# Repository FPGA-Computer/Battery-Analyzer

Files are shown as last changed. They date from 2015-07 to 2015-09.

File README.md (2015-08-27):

This is a Dual Channel Battery Analyzer for HaD 2015 Contest Entry.

+ Ver 2.1 Rel 0/	
|  |Initial PCB release - first layout/non-tested
|  |
|  + Eagle PCB/
|  | Eagle CAd files
|  |
|  + Sketch3D/
|  | Sketch3D model
|  |
|  + LTSpice/
|    Linear Tech Spice Simulation analog file
|
+ Windows/
| Pelles C Project file
|
+ Firmware/
  Simplicity Studio files

Hackaday project page is at 
https://hackaday.io/project/4993-dual-channel-battery-chargeranalyzer

The hardware design is under a Creative Commons Attribution-
NonCommercial-ShareAlike 4.0 International License.

The full detail of this license is available at: 
http://creativecommons.org/licenses/by-nc-sa/4.0/

The software is under Mozilla Public License
The full detail of this license is available at: 
https://www.mozilla.org/MPL/

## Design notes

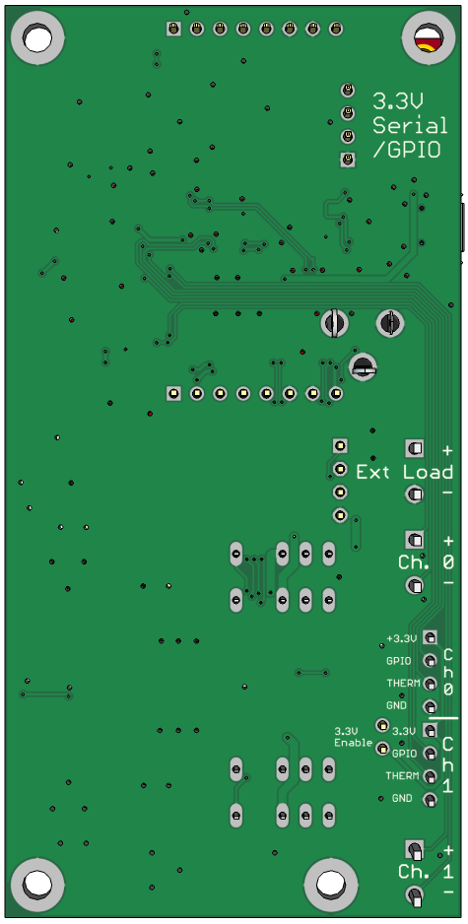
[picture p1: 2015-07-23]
Ver 2.1 Rel 0/Sketch3D/pcb-bot.png

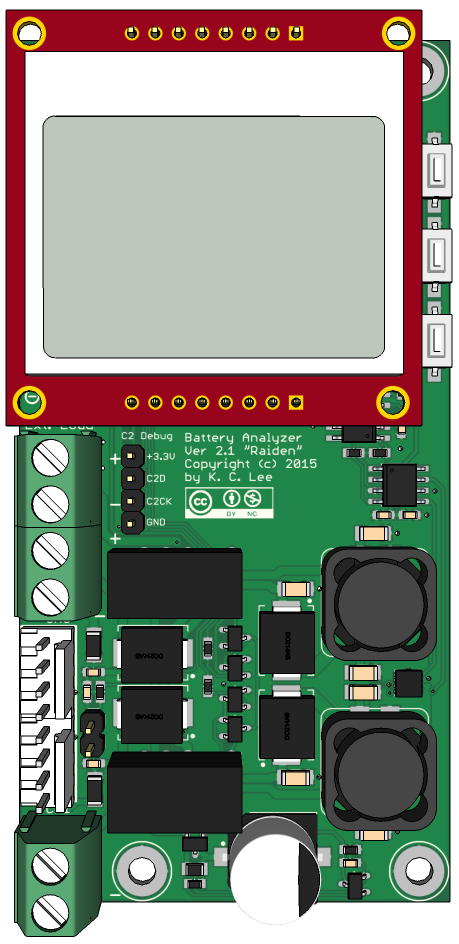
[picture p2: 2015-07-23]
Ver 2.1 Rel 0/Sketch3D/PCB-top.png

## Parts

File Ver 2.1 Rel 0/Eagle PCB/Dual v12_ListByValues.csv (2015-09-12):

Qty | Value | Part Num | Package | Parts
1 |  | BG: SKU038984 | 1X02 | J2
1 |  | BG: SKU038984 | 1X04 | JP1
1 |  | DX: SKU134132 | USB-AB-MICRO-SMD_V03_SF | U1
1 |  | STOCK | 1X04-RA | JP2
4 | 0.01uF | DK: 311-1085-1-ND | CAPC1608X92N | C20, C21, C22, C23
2 | 0R1 .25W | STOCK: DK73L4R10JCT-ND | RESC3115X70N | R18, R21
12 | 0u1 | STOCK: DK 490-1532-1-ND | CAPC1608X92N | C2, C6, C7, C13, C15, C16, C17, C18, C19, C24, C33, C34
5 | 0u1 | STOCK: DK 587-1227-1-ND | CAPC1005X60N | C5, C29, C30, C31, C32
2 | 0u15/50V | STOCK: 0.15UF/50V10% | CAP2012X70N | C1, C12
1 | 1K | DK: 311-1.00KLRCT-ND | RESC1005X40AN | R5
1 | 1K | STOCK: DK 1276-3484-1-ND | RESC1608X55N | R4
4 | 1K2 | STOCK: 1K21 1% | RESC1608X55N | R7, R26, R28, R29
2 | 1K5 | STOCK: DKRHM1.50KCFCT-ND | RESC1608X55N | R17, R20
1 | 1nF | DK: 311-1080-1-ND | CAPC1608X92N | C25
2 | 1uF | DK: 490-10435-1-ND | CAPC1005X60N | C3, C4
4 | 1uF | STOCK: 1UF/10V 20% TDK | CAPC1608X92N | C10, C26, C27, C35
3 | 1uF/25V | DK: 311-1456-1-ND | CAP2012X70N | C9, C11, C14
2 | 4K7 | STOCK:4K75 1% | RESC1608X55N | R14, R27
1 | 8K2 | STOCK | CAT16 | RN2
10 | 10K | STOCK: 10K 1% | RESC1608X55N | R2, R16, R19, R24, R25, R31, R33, R34, R35, R36
2 | 10K | STOCK: DK CAY16-103J4GLFCT-ND | CAT16 | RN3, RN4
1 | 10R | STOCK: 10R 1% | RESC1608X55N | R15
1 | 10uF/6.3V | DK: 490-5525-1-ND | CAP2012X70N | C42
2 | 10uF/16V | DK: 490-5525-1-ND | CAPC3215X168N | C37, C39
2 | 10uF/25V | DK: 490-5525-1-ND | CAPC3215X168N | C40, C41
2 | 10uF/35V | DK: 490-9964-1-ND | CAPC3215X168N | C36, C38
1 | 13K0 | DK: 311-13.0KHRCT-ND | RESC1608X55N | R9
2 | 22-23-2041 | DK: A19431-ND | 22-23-2041 | J4, J5
2 | 22R | STOCK: DK 1276-3497-1-ND | RESC1608X55N | R1, R3
1 | 22pF | STOCK: 22PF | CAPC1608X92N | C28
5 | 39K2 | DK: 311-39.2KHRCT-ND | RESC1608X55N | R12, R22, R23, R32, R37
1 | 100K | STOCK: DK311-100KHRCT-ND | RESC1608X55N | R6
2 | 100R | STOCK | RESC1608X55N | R11, R13
1 | 100R | STOCK | RESC2012X70N | R8
1 | 470R | DK: YC164J-470CT-ND | CAT16 | RN1
1 | 470uF/25V | STOCK | CAPAE1030X1020N | C8
1 | 475K | STOCK: P475KHCT-ND | RESC1608X55N | R10
1 | 475R | STOCK: DK 1276-4620-1-ND | RESC1608X55N | R30
1 | AON7804 | DK: 785-1586-1-ND | DFN3X3 | Q7
1 | AP3012 | DK: AP3012KTR-G1DICT-ND | SOT23-5 | U3
1 | BAT54C | STOCK | SOT95P280X135-3N | D3
1 | CC100% | * | CC-100 | U$1
1 | CCNONE | * | CC-NONE | U$2
2 | CD54NP-100MC | DK: 587-1626-1-ND | CD54 | L1, L2
1 | DCJ0202PIN | STOCK: DK CP-102A-ND | PJ-102A | J1
1 | EFM8UB1X-QFN28 | DK: 336-3183-5-ND | QFN-28 | U2
2 | G6N-2-Y | STOCK | NA | K1, K2
1 | LM339D | STOCK | SO14 | U5
6 | MBRS430 | STOCK | DIOM7959X265N | D1, D2, D10, D11, D12, D13
3 | MMBT2222 | STOCK: MMBT2222 | SOT95P280X135-3N | Q3, Q5, Q6
2 | MMBT3906 | STOCK:MMBT3906 | SOT95P280X135-3N | Q1, Q4
3 | MOM_SW__1181 | BG: SKU156899 | MOM-1181 | S1, S2, S3
4 | MOUNT-PAD-ROUND3.2 | * | 3,2-PAD | H1, H2, H3, H4
1 | NOKIA5110 | BG: SKU091069 | NOKIA5110-BOTH | U4
1 | POLARITY | * | POLARITY | U$3
3 | SCREW-TERM_5MM_BG | BG: SKU170379 | 1X02-5MM-BG | J3, J6, J7
2 | SRF1260-100M | DK: SRF1260-100MCT-ND | SRF1260 | L3, L4
1 | STPS130A | DK: 497-3755-1-ND | DIOM5326X292N | D4
4 | Si SW | STOCK: BAV99 | SOT95P280X135-3N | D6, D7, D8, D9
1 | Si2307 | STOCK: SI2307DS | SOT95P280X135-3N | Q2
1 | TC4426ACOA | DK: TC4426ACOA-ND | SOIC8 | U6
1 | TPSQTP08R | * | TP08R | TP1
2 | TPSQTP14SQ | * | TP14SQ | TP2, TP3
1 | Z12V | STOCK | SOT95P280X135-3N | D5

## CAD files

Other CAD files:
Windows/charger21/output/debug.obj
Windows/charger21/output/usb host.obj
Windows/charger21/output/Charger gui.obj
Windows/charger21/output/data.obj
Windows/charger21/output/Battery gui.obj
Windows/charger21/output/charger.obj
Windows/charger21/output/gui support.obj
Windows/charger21/output/fileop.obj
Windows/charger21/output/tabmenu.obj

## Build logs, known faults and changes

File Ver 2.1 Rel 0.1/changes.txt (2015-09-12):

- Fixed connections with VBUS detection
- 0402 parts switched to 0603 and cap array.
- todo need new lcd footprint

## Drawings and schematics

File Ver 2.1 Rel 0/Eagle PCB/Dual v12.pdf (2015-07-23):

A

A

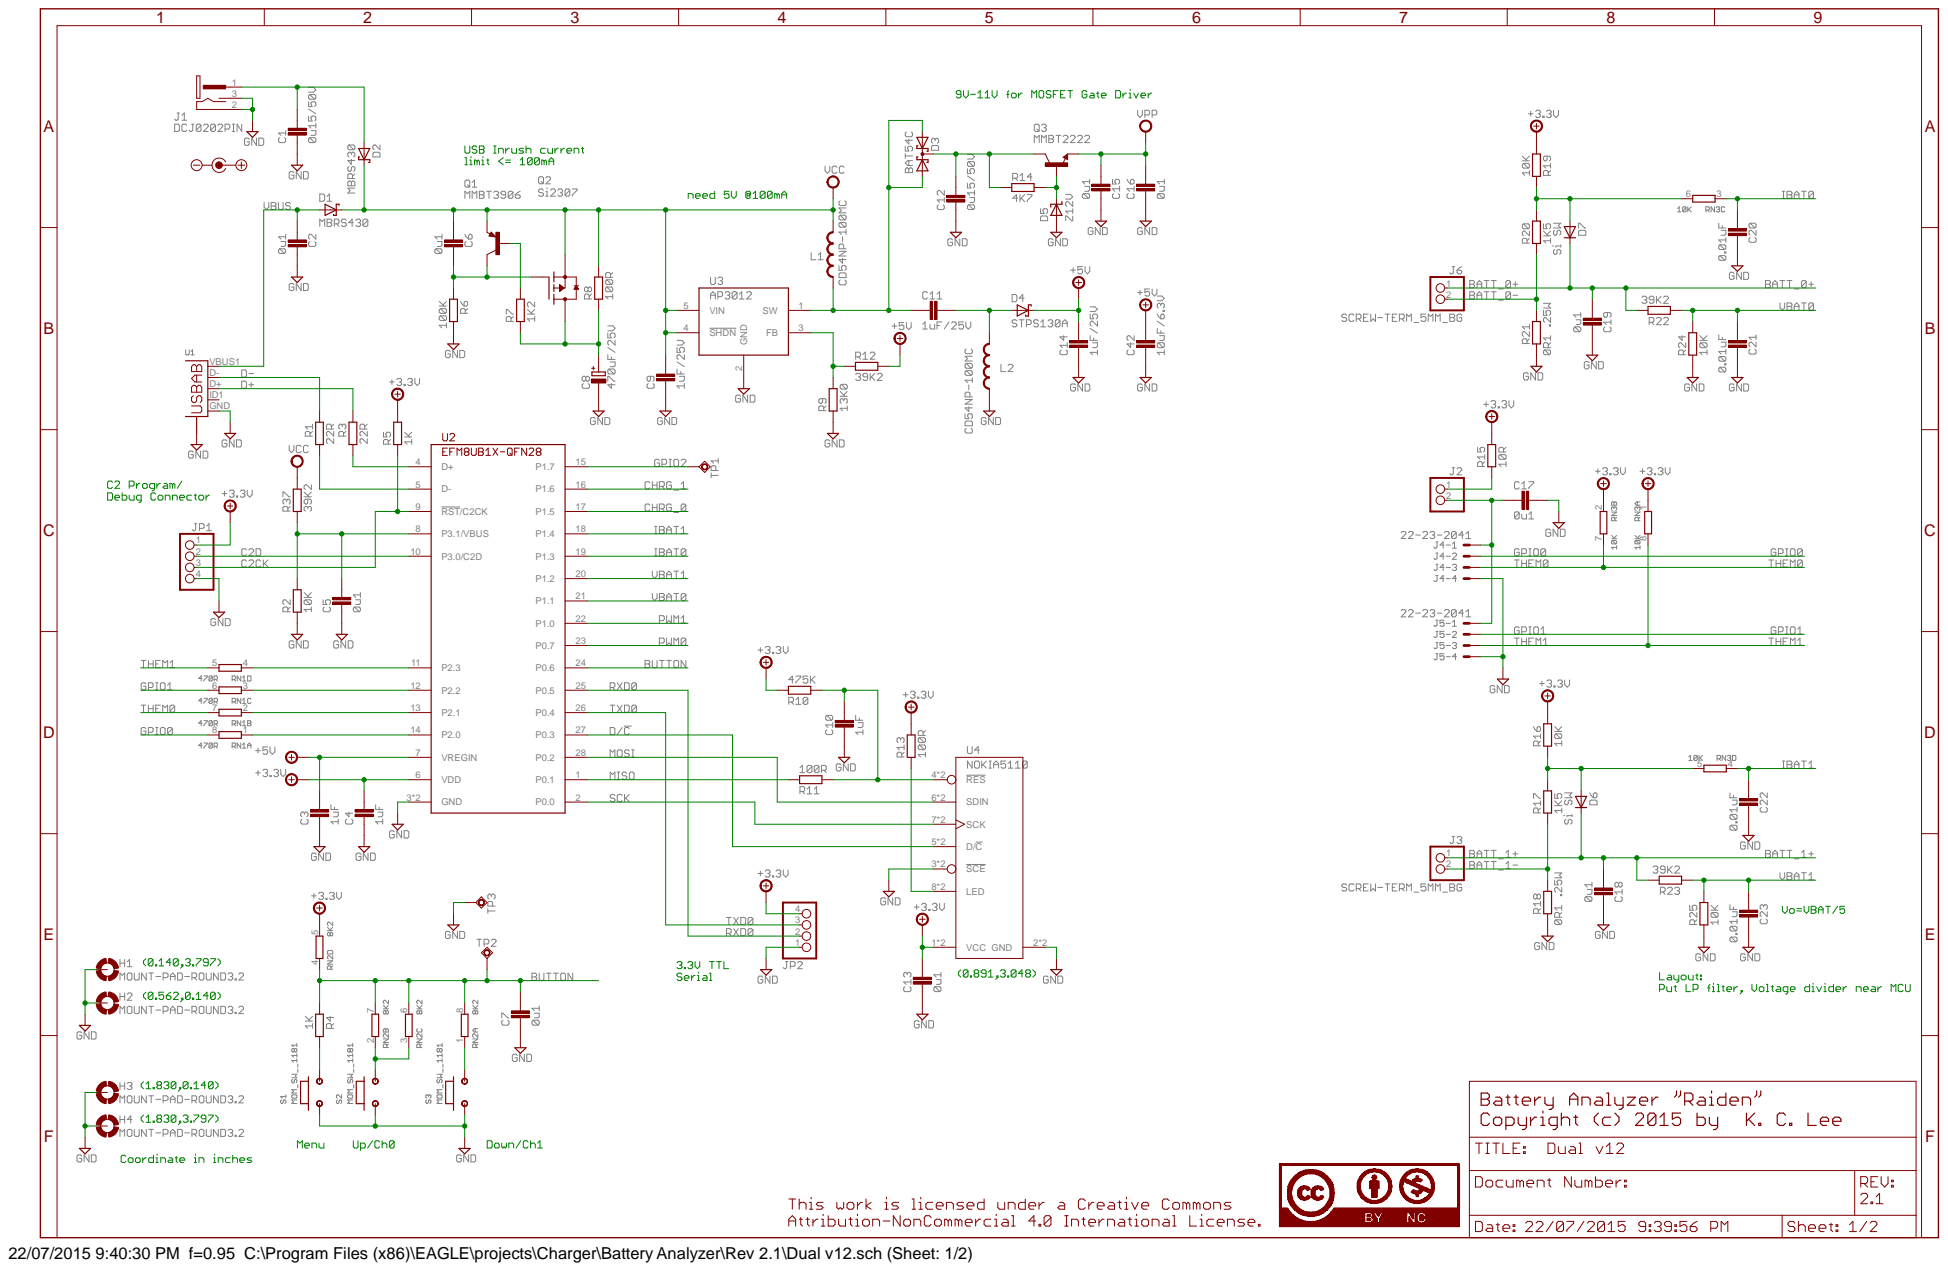
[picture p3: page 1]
SCE 3*2; RES 4*2; SDIN 6*2; SCK 7*2; LED 8*2; VCC 1*2; GND; VBUS1; VIN 5; SHDN 4; P3.1/VBUS 8; RST/C2CK 9; VREGIN 7; VDD 6; GND 3*2

22/07/2015 9:40:30 PM f=0.95 C:\Program Files (x86)\EAGLE\projects\Charger\Battery Analyzer\Rev 2.1\Dual v12.sch (Sheet: 1/2)

A

A

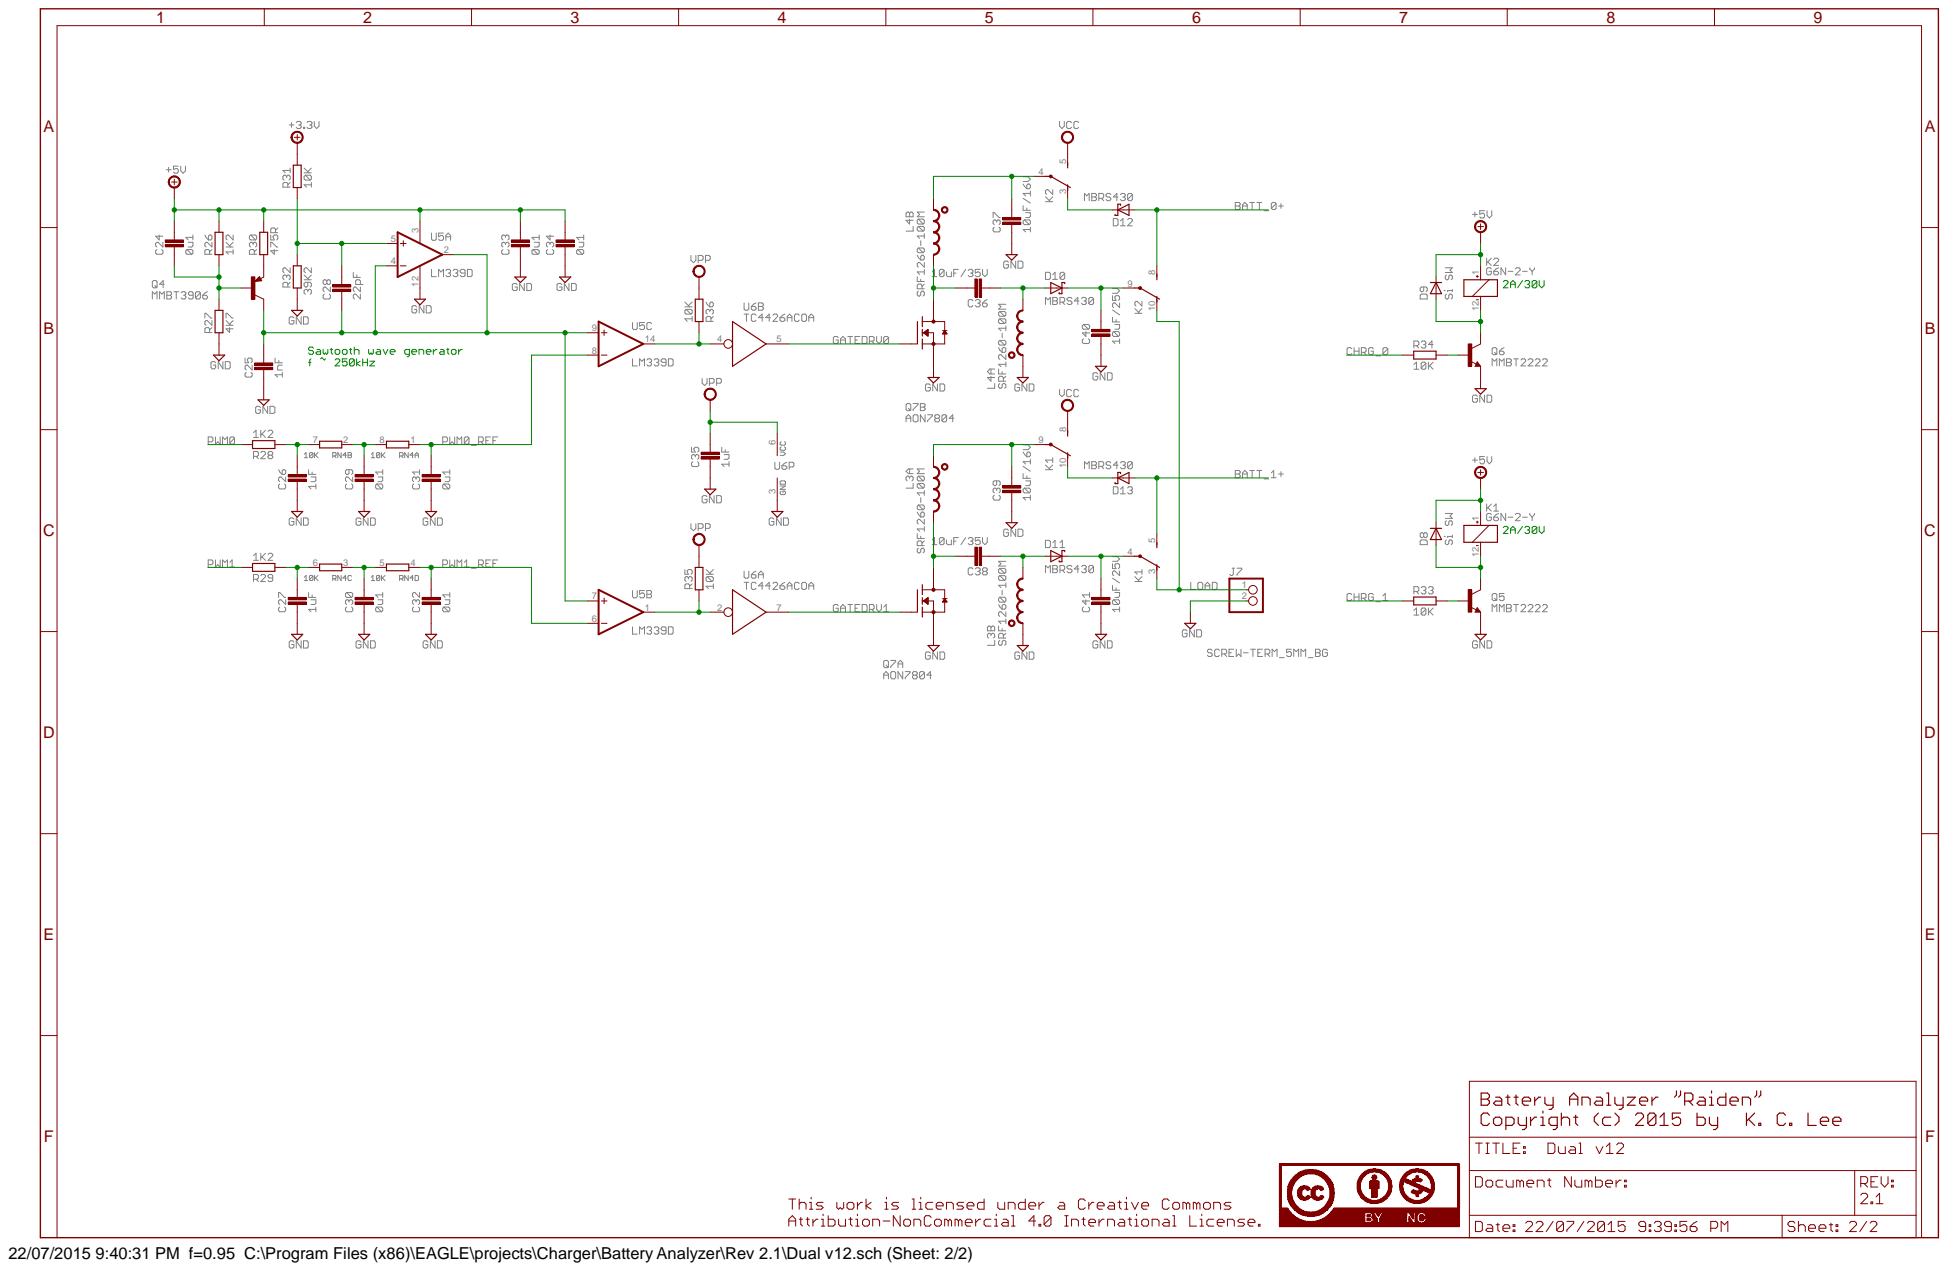
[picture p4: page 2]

22/07/2015 9:40:31 PM f=0.95 C:\Program Files (x86)\EAGLE\projects\Charger\Battery Analyzer\Rev 2.1\Dual v12.sch (Sheet: 2/2)

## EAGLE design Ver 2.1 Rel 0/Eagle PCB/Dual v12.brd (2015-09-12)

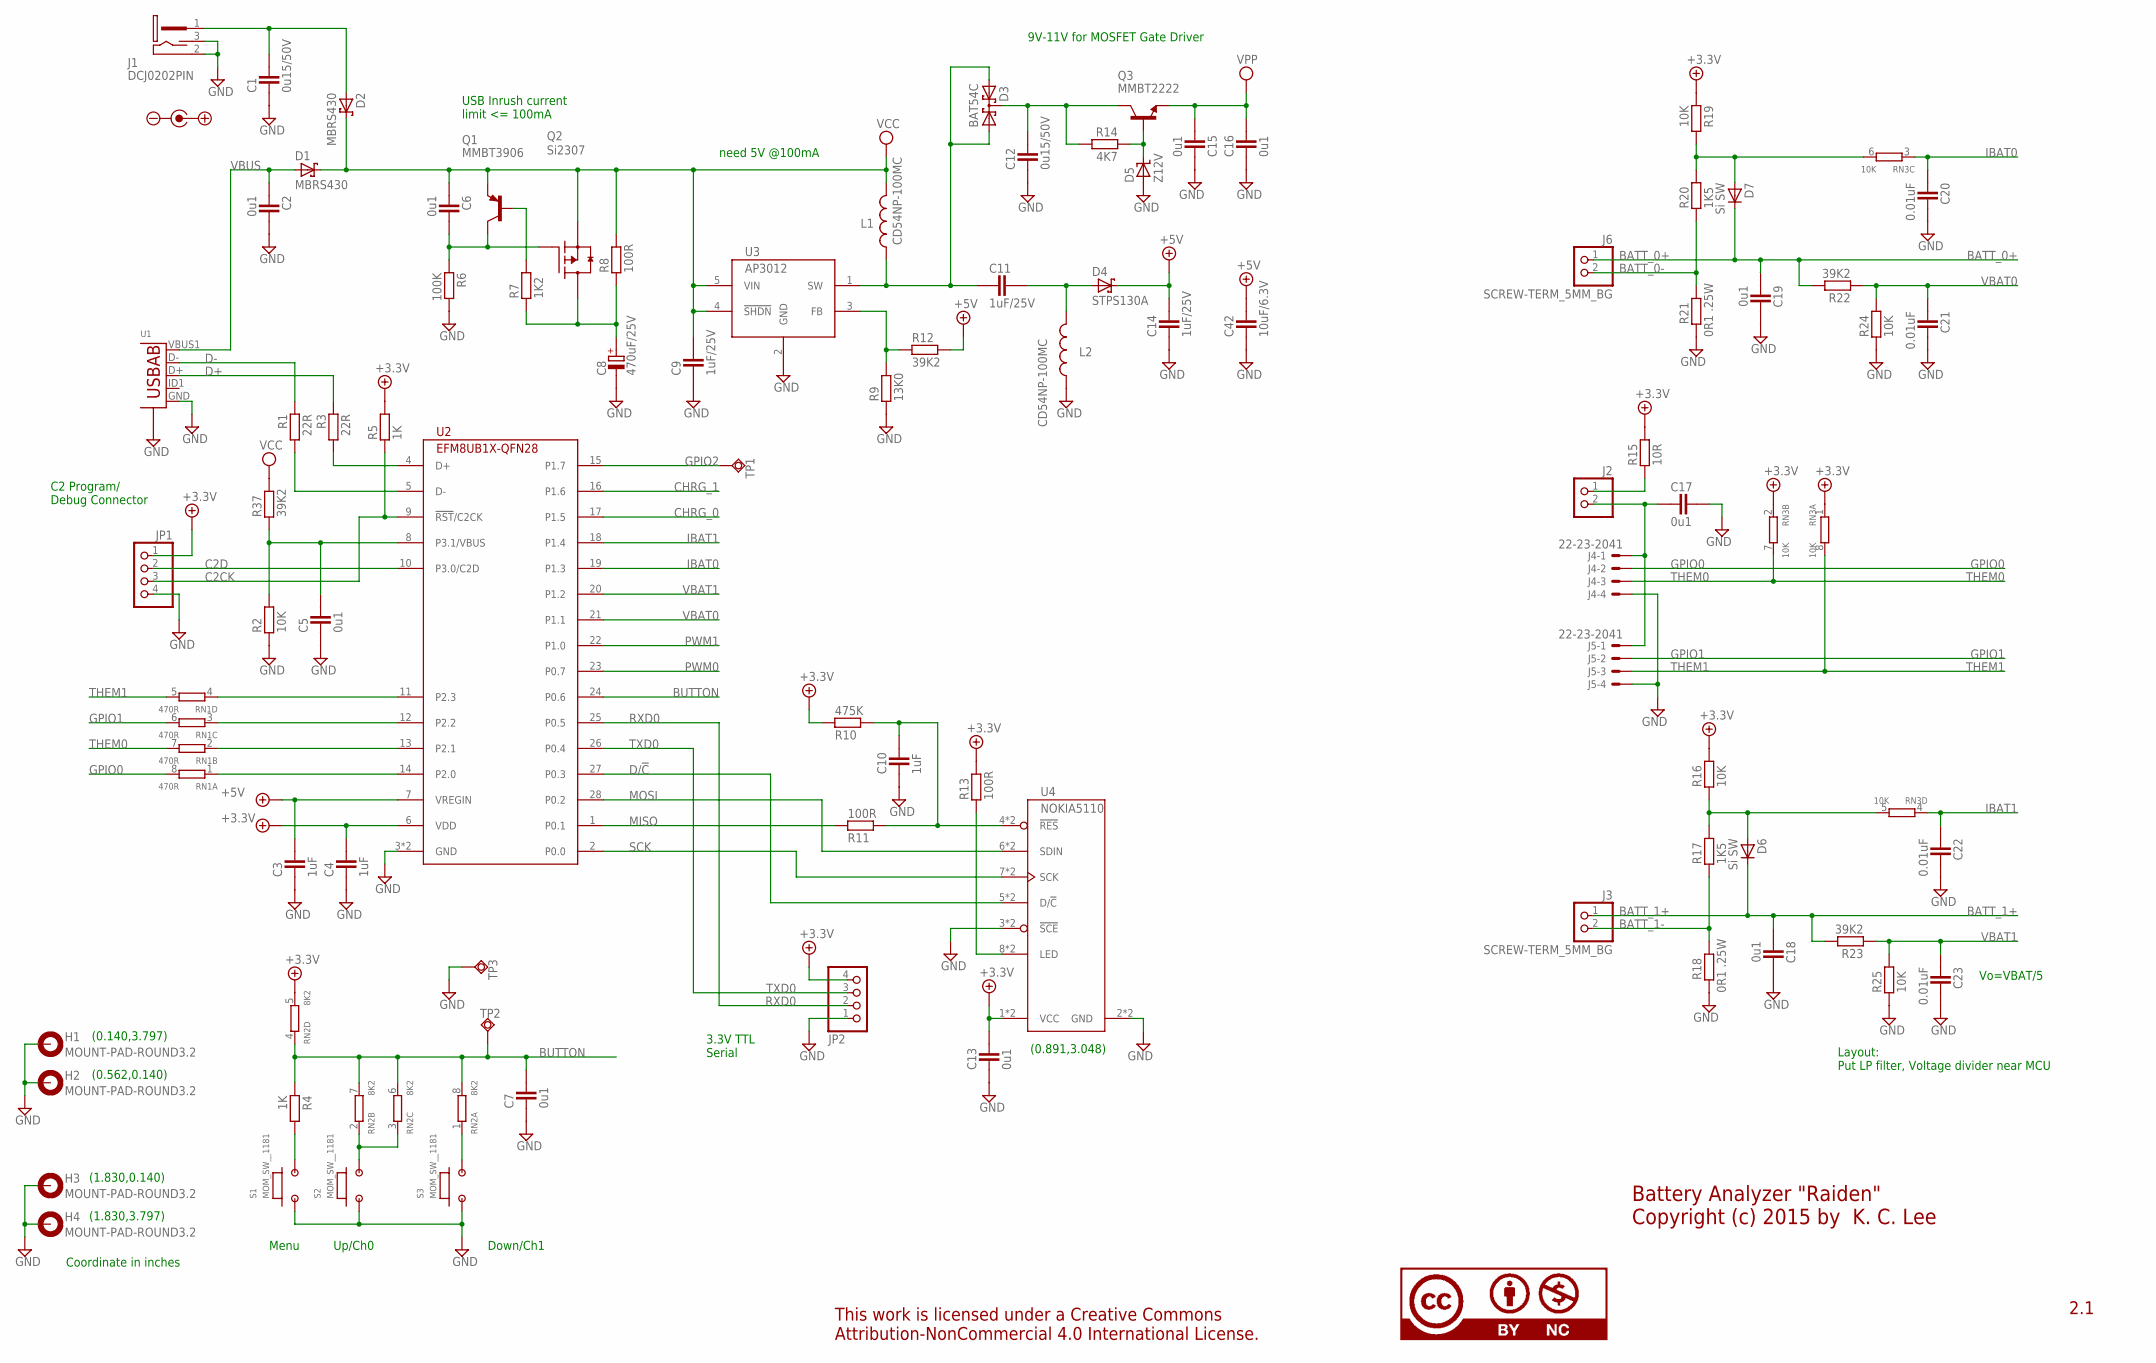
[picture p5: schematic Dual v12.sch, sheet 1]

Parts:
C1, C12: 0u15/50V; CAP2012X70N; PARTNO STOCK: 0.15UF/50V10%
C2, C6, C7, C13, C15, C16, C17, C18, C19: 0u1; CAPC1608X92N; PARTNO STOCK: DK 490-1532-1-ND
C3, C4: 1uF; CAPC1005X60N; PARTNO DK: 490-10435-1-ND
C5: 0u1; CAPC1005X60N; PARTNO STOCK: DK 587-1227-1-ND
C8: 470uF/25V; CAPAE1030X1020N; PARTNO STOCK
C9, C11, C14: 1uF/25V; CAP2012X70N; PARTNO DK: 311-1456-1-ND
C10: 1uF; CAPC1608X92N; PARTNO STOCK: 1UF/10V 20% TDK
C20, C21, C22, C23: 0.01uF; CAPC1608X92N; PARTNO DK: 311-1085-1-ND
C42: 10uF/6.3V; CAP2012X70N; PARTNO DK: 490-5525-1-ND
D1, D2: MBRS430; DIOM7959X265N; PARTNO STOCK
D3: BAT54C; SOT95P280X135-3N; PARTNO STOCK
D4: STPS130A; DIOM5326X292N; PARTNO DK: 497-3755-1-ND
D5: Z12V; SOT95P280X135-3N; PARTNO STOCK
D6, D7: Si SW; SOT95P280X135-3N; PARTNO STOCK: BAV99
H1, H2, H3, H4: MOUNT-PAD-ROUND3.2; 3,2-PAD; PARTNO *
J1: DCJ0202PIN; PJ-102A; PARTNO STOCK: DK CP-102A-ND
J2: PINHD-1X2_2.54; 1X02; PARTNO BG: SKU038984
J3, J6: SCREW-TERM_5MM_BG; 1X02-5MM-BG; PARTNO BG: SKU170379
J4, J5: 22-23-2041; PARTNO DK: A19431-ND
JP1: PINHD-1X4_2.54; 1X04; PARTNO BG: SKU038984
JP2: PINHD-1X4_2.54-90°; 1X04-RA; PARTNO STOCK
L1, L2: CD54NP-100MC; CD54; PARTNO DK: 587-1626-1-ND
Q1: MMBT3906; SOT95P280X135-3N; PARTNO STOCK:MMBT3906
Q2: Si2307; SOT95P280X135-3N; PARTNO STOCK: SI2307DS
Q3: MMBT2222; SOT95P280X135-3N; PARTNO STOCK: MMBT2222
R1, R3: 22R; RESC1608X55N; PARTNO STOCK: DK 1276-3497-1-ND
R2, R16, R19, R24, R25: 10K; RESC1608X55N; PARTNO STOCK: 10K 1%
R4: 1K; RESC1608X55N; PARTNO STOCK: DK 1276-3484-1-ND
R5: 1K; RESC1005X40AN; PARTNO DK: 311-1.00KLRCT-ND
R6: 100K; RESC1608X55N; PARTNO STOCK: DK311-100KHRCT-ND
R7: 1K2; RESC1608X55N; PARTNO STOCK: 1K21 1%
R8: 100R; RESC2012X70N; PARTNO STOCK
R9: 13K0; RESC1608X55N; PARTNO DK: 311-13.0KHRCT-ND
R10: 475K; RESC1608X55N; PARTNO STOCK: P475KHCT-ND
R11, R13: 100R; RESC1608X55N; PARTNO STOCK
R12, R22, R23, R37: 39K2; RESC1608X55N; PARTNO DK: 311-39.2KHRCT-ND
R14: 4K7; RESC1608X55N; PARTNO STOCK:4K75 1%
R15: 10R; RESC1608X55N; PARTNO STOCK: 10R 1%
R17, R20: 1K5; RESC1608X55N; PARTNO STOCK: DKRHM1.50KCFCT-ND
R18, R21: 0R1 .25W; RESC3115X70N; PARTNO STOCK: DK73L4R10JCT-ND
RN1: 470R; CAT16; PARTNO DK: YC164J-470CT-ND
RN2: 8K2; CAT16; PARTNO STOCK
RN3: 10K; CAT16; PARTNO STOCK: DK CAY16-103J4GLFCT-ND
S1, S2, S3: MOM_SW__1181; MOM-1181; PARTNO BG: SKU156899
TP1: TPSQTP08R; TP08R; PARTNO *
TP2, TP3: TPSQTP14SQ; TP14SQ; PARTNO *
U1: USB-ABBG; USB-AB-MICRO-SMD_V03_SF; PARTNO DX: SKU134132
U2: EFM8UB1X-QFN28; QFN-28; PARTNO DK: 336-3183-5-ND
U3: AP3012; SOT23-5; PARTNO DK: AP3012KTR-G1DICT-ND
U4: NOKIA5110; NOKIA5110-BOTH; PARTNO BG: SKU091069
U$1: CC100%; CC-100; PARTNO *
U$3: POLARITY; PARTNO *

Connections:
+3.3V: C4.2, C13.2, JP1.1, JP2.4, R5.2, R10.1, R13.2, R15.2, R16.2, R19.1, RN2.5 (2), RN3.1, RN3.2 (1), U2.6 (VDD), U4.1 (VCC), U4.9 (VCC); also elsewhere on the board
+5V: C3.2, C14.2, C42.2, D4.K, R12.2, U2.7 (VREGIN); also elsewhere on the board
BATT_0+: C19.1, D7.3 (K), J6.1, R22.2; also elsewhere on the board
BATT_0-: J6.2, R20.1, R21.2
BATT_1+: C18.1, D6.3 (K), J3.1, R23.2; also elsewhere on the board
BATT_1-: J3.2, R17.1, R18.2
BUTTON: C7.2, R4.1, RN2.4 (1), RN2.6 (2), RN2.7 (2), RN2.8 (2), TP2.TP, U2.24 (P0.6)
C2CK: JP1.3, R5.1, U2.9 (!RST!/C2CK)
C2D: JP1.2, U2.10 (P3.0/C2D)
CHRG_0: U2.17 (P1.5); also elsewhere on the board
CHRG_1: U2.16 (P1.6); also elsewhere on the board
D+: R3.1, U1.D+
D-: R1.1, U1.D-
D/!C: U2.27 (P0.3), U4.5 (D/!C), U4.13 (D/!C)
GND: C1.1, C2.2, C3.1, C4.1, C5.1, C7.1, C8.-, C9.1, C10.1, C12.1, C13.1, C14.1, C15.1, C16.1, C17.2, C18.2, C19.2, C20.2, C21.2, C22.2, C23.2, C42.1, D5.1 (A), H1.B3,2, H2.B3,2, H3.B3,2, H4.B3,2, J1.2 (3), J1.3 (2), J4.4, J5.4, JP1.4, JP2.1, L2.1, R2.1, R6.2, R9.1, R18.1, R21.1, R24.1, R25.1, S1.1, S2.1, S3.1, TP3.TP, U1.GND, U1.S1 (S), U1.S2 (S), U1.S3 (S), U1.S4 (S), U2.3 (GND), U2.PAD (GND), U3.2 (GND), U4.2 (GND), U4.3 (!SCE), U4.10 (GND), U4.11 (!SCE); also elsewhere on the board
GPIO0: J4.2, RN1.8 (2)
GPIO1: J5.2, RN1.6 (2)
GPIO2: TP1.TP, U2.15 (P1.7)
IBAT0: C20.1, RN3.3 (1), U2.19 (P1.3)
IBAT1: C22.1, RN3.4 (1), U2.18 (P1.4)
MISO: R11.1, U2.1 (P0.1)
MOSI: U2.28 (P0.2), U4.6 (SDIN), U4.14 (SDIN)
unnamed: C6.2, Q1.3 (C), Q2.1 (G), R6.1
unnamed: C10.2, R10.2, R11.2, U4.4 (!RES), U4.12 (!RES)
unnamed: Q1.1 (B), R7.2
unnamed: R13.1, U4.8 (LED), U4.16 (LED)
unnamed: RN1.1, U2.14 (P2.0)
unnamed: C1.2, D2.A, J1.1
unnamed: D5.3 (K), Q3.1 (B), R14.1
unnamed: C11.1, D3.1 (A1), D3.2 (A2), L1.1, U3.1 (SW)
unnamed: C8.+, Q2.3 (D), R7.1, R8.1
unnamed: C11.2, D4.A, L2.2
unnamed: R3.2, U2.4 (D+)
unnamed: C12.2, D3.3 (CC), Q3.3 (C), R14.2
unnamed: R9.2, R12.1, U3.3 (FB)
unnamed: C5.2, R2.2, R37.1, U2.8 (P3.1/VBUS)
unnamed: R1.2, U2.5 (D-)
unnamed: RN1.2 (1), U2.13 (P2.1)
unnamed: R4.2, S1.2
unnamed: RN1.3 (1), U2.12 (P2.2)
unnamed: RN1.4 (1), U2.11 (P2.3)
unnamed: C17.1, J2.2, J4.1, J5.1
unnamed: RN2.2 (1), RN2.3 (1), S2.2
unnamed: J2.1, R15.1
unnamed: RN2.1, S3.2
unnamed: D6.1 (A), R16.1, R17.2, RN3.5 (2)
unnamed: D7.1 (A), R19.2, R20.2, RN3.6 (2)
PWM0: U2.23 (P0.7); also elsewhere on the board
PWM1: U2.22 (P1.0); also elsewhere on the board
RXD0: JP2.2, U2.25 (P0.5)
SCK: U2.2 (P0.0), U4.7 (SCK), U4.15 (SCK)
THEM0: J4.3, RN1.7 (2), RN3.7 (2)
THEM1: J5.3, RN1.5 (2), RN3.8 (2)
TXD0: JP2.3, U2.26 (P0.4)
VBAT0: C21.1, R22.1, R24.2, U2.21 (P1.1)
VBAT1: C23.1, R23.1, R25.2, U2.20 (P1.2)
VBUS: C2.1, D1.A, U1.VBUS1 (VBUS)
VCC: C6.1, C9.2, D1.K, D2.K, L1.2, Q1.2 (E), Q2.2 (S), R8.2, R37.2, U3.4 (!SHDN), U3.5 (VIN); also elsewhere on the board
VPP: C15.2, C16.2, Q3.2 (E); also elsewhere on the board

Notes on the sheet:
USB Inrush current limit <= 100mA
need 5V @100mA
C2 Program/ Debug Connector
3.3V TTL Serial
Vo=VBAT/5
(0.140,3.797)
(0.562,0.140)
(1.830,0.140)
(1.830,3.797)
Layout: Put LP filter, Voltage divider near MCU
Menu
Up/Ch0
Down/Ch1
Battery Analyzer "Raiden" Copyright (c) 2015 by K. C. Lee
9V-11V for MOSFET Gate Driver
2.1
Coordinate in inches
(0.891,3.048)

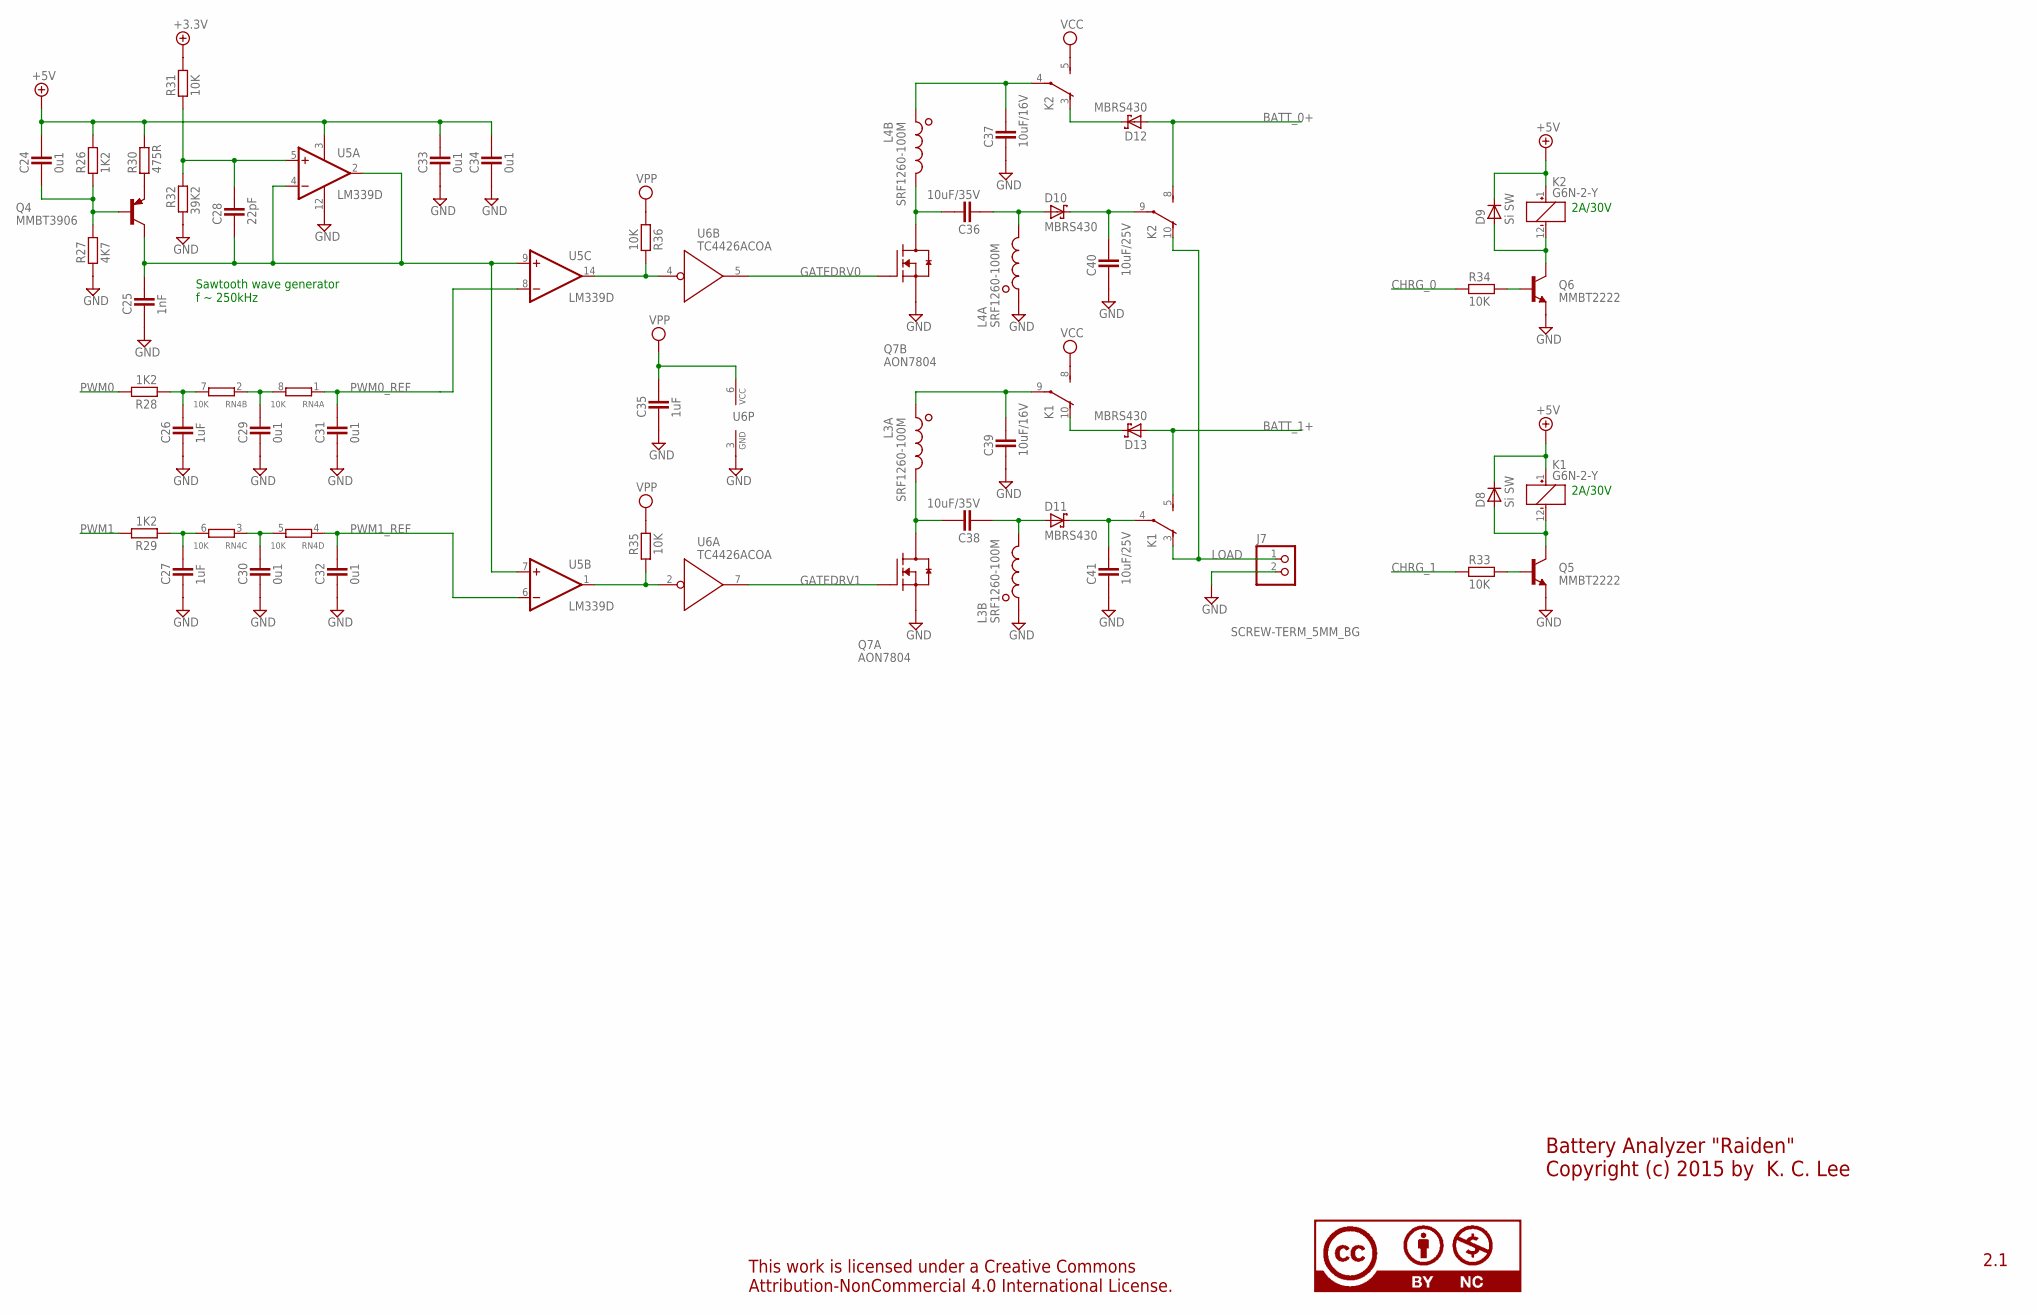
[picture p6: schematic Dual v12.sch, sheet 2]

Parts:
C24, C33, C34: 0u1; CAPC1608X92N; PARTNO STOCK: DK 490-1532-1-ND
C25: 1nF; CAPC1608X92N; PARTNO DK: 311-1080-1-ND
C26, C27, C35: 1uF; CAPC1608X92N; PARTNO STOCK: 1UF/10V 20% TDK
C28: 22pF; CAPC1608X92N; PARTNO STOCK: 22PF
C29, C30, C31, C32: 0u1; CAPC1005X60N; PARTNO STOCK: DK 587-1227-1-ND
C36, C38: 10uF/35V; CAPC3215X168N; PARTNO DK: 490-9964-1-ND
C37, C39: 10uF/16V; CAPC3215X168N; PARTNO DK: 490-5525-1-ND
C40, C41: 10uF/25V; CAPC3215X168N; PARTNO DK: 490-5525-1-ND
D8, D9: Si SW; SOT95P280X135-3N; PARTNO STOCK: BAV99
D10, D11, D12, D13: MBRS430; DIOM7959X265N; PARTNO STOCK
J7: SCREW-TERM_5MM_BG; 1X02-5MM-BG; PARTNO BG: SKU170379
K1, K2: G6N-2-Y; NA; PARTNO STOCK
L3, L4: SRF1260-100M; SRF1260; PARTNO DK: SRF1260-100MCT-ND
Q4: MMBT3906; SOT95P280X135-3N; PARTNO STOCK:MMBT3906
Q5, Q6: MMBT2222; SOT95P280X135-3N; PARTNO STOCK: MMBT2222
Q7: AON7804; DFN3X3; PARTNO DK: 785-1586-1-ND
R26, R28, R29: 1K2; RESC1608X55N; PARTNO STOCK: 1K21 1%
R27: 4K7; RESC1608X55N; PARTNO STOCK:4K75 1%
R30: 475R; RESC1608X55N; PARTNO STOCK: DK 1276-4620-1-ND
R31, R33, R34, R35, R36: 10K; RESC1608X55N; PARTNO STOCK: 10K 1%
R32: 39K2; RESC1608X55N; PARTNO DK: 311-39.2KHRCT-ND
RN4: 10K; CAT16; PARTNO STOCK: DK CAY16-103J4GLFCT-ND
U5: LM339D; SO14; PARTNO STOCK
U6: TC4426ACOA; SOIC8; PARTNO DK: TC4426ACOA-ND
U$2: CCNONE; CC-NONE; PARTNO *

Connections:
+3.3V: R31.2; also elsewhere on the board
+5V: C24.2, C33.2, C34.2, D8.3 (K), D9.3 (K), K1.1 (+), K2.1 (+), R26.2, R30.2, U5.3 (V+); also elsewhere on the board
BATT_0+: D12.A, K2.8 (S); also elsewhere on the board
BATT_1+: D13.A, K1.5 (S); also elsewhere on the board
CHRG_0: R34.1; also elsewhere on the board
CHRG_1: R33.1; also elsewhere on the board
GATEDRV0: Q7.G2 (G), U6.5 (OUT)
GATEDRV1: Q7.G1 (G), U6.7 (OUT)
GND: C25.1, C26.1, C27.1, C29.1, C30.1, C31.1, C32.1, C33.1, C34.1, C35.1, C37.1, C39.1, C40.1, C41.1, J7.2, L3.2 (1), L4.1, Q5.2 (E), Q6.2 (E), Q7.S1 (S), Q7.S2 (S), R27.1, R32.2, U5.12 (GND), U6.3 (GND); also elsewhere on the board
LOAD: J7.1, K1.3 (O), K2.10 (O)
unnamed: D8.1 (A), K1.12 (-), Q5.3 (C)
unnamed: D13.K, K1.10 (O)
unnamed: D9.1 (A), K2.12 (-), Q6.3 (C)
unnamed: C28.2, R31.1, R32.1, U5.5 (+IN)
unnamed: Q6.1 (B), R34.2
unnamed: Q5.1 (B), R33.2
unnamed: D12.K, K2.3 (O)
unnamed: C30.2, RN4.3 (1), RN4.5 (2)
unnamed: C26.2, R28.1, RN4.7 (2)
unnamed: C27.2, R29.1, RN4.6 (2)
unnamed: C29.2, RN4.2 (1), RN4.8 (2)
unnamed: C38.2, L3.3 (2), Q7.D1@1 (D), Q7.D1@2 (D)
unnamed: C24.1, Q4.1 (B), R26.1, R27.2
unnamed: Q4.2 (E), R30.1
unnamed: C25.2, C28.1, Q4.3 (C), U5.2 (OUT), U5.4 (-IN), U5.7 (+IN), U5.9 (+IN)
unnamed: C36.2, L4.4 (2), Q7.D2@1 (D), Q7.D2@2 (D)
unnamed: C38.1, D11.A, L3.4 (2)
unnamed: C36.1, D10.A, L4.3 (2)
unnamed: C37.2, K2.4, L4.2 (1)
unnamed: C40.2, D10.K, K2.9
unnamed: C41.2, D11.K, K1.4
unnamed: C39.2, K1.9, L3.1
PWM0: R28.2; also elsewhere on the board
PWM0_OUT: R35.2, U5.1 (OUT), U6.2 (!IN)
PWM0_REF: C31.2, RN4.1, U5.8 (-IN)
PWM1: R29.2; also elsewhere on the board
PWM1_OUT: R36.1, U5.14 (OUT), U6.4 (!IN)
PWM1_REF: C32.2, RN4.4 (1), U5.6 (-IN)
VCC: K1.8 (S), K2.5 (S); also elsewhere on the board
VPP: C35.2, R35.1, R36.2, U6.6 (VCC); also elsewhere on the board

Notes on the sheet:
Sawtooth wave generator f ~ 250kHz
2A/30V
Battery Analyzer "Raiden" Copyright (c) 2015 by K. C. Lee
2.1

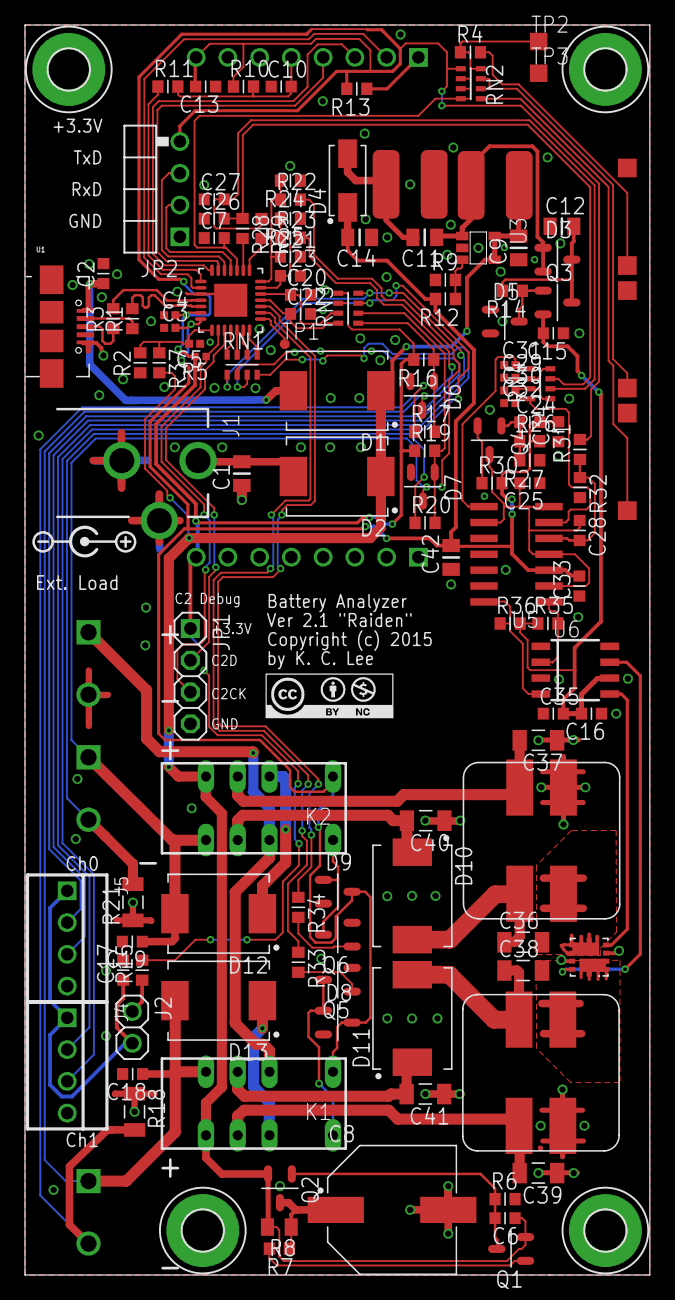
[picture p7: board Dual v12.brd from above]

Board: 2 copper layers, 50.0 x 100.0 mm, 137 parts (0 on the bottom side), 88 nets.

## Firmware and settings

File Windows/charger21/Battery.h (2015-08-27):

/*
 * Battery.h
 *
 * Created: 10/07/2013 5:16:40 PM
 *  Author: K. C. Lee
 * Copyright (c) 2015 by K. C. Lee
 *
 * The software is under Mozilla Public License
 * The full detail of this license is available at: 
 * https://www.mozilla.org/MPL/
 */ 

#ifndef BATTERY_H_
#define BATTERY_H_

#include "pcb.h"

enum ChargeAlgorithm { ALG_Unknown, ALG_CC_CV, ALG_NiMH, ALG_NiCd,  };

enum ChargeStates
{ Charge_Unknown, Charge_Select,
  Charge_Fault, Charge_BadBattery, Charge_NoBattery, Charge_Reverse, Charge_OverCurrent,
  Charge_Ready, Charge_Precharge, Charge_ConstantV, Charge_ConstantI, Charge_Full, Charge_Trickle
 };

#define BATTERY_NAME_LEN	4
#define Alg_None                Alg_Strings[0]

typedef struct  
{
  char	    Name[BATTERY_NAME_LEN+1];
  int8_t    Algorithm;
  uint16_t  Capacity;           // capacity in mA*Hr
  uint16_t  Precharge_V;        // Minimum voltage for charging
  uint16_t  Charge_V;           // Charging voltage
  uint16_t  TopUp_V;            // Top up voltage

  uint16_t  Precharge_I;        // Precharge current in C
  uint16_t  Charge_I;           // Charge current in C
  uint16_t  Term_I;             // Termination current in C
  uint16_t  TopUp_I;            // Top up current in C

/*
  uint8_t   Temp_Min;           // Temperature min
  uint8_t   Temp_Max;           // Temperature max
*/
  
 } BatteryType;

typedef struct  
{ BatteryType   Battery;
  uint8_t       BattIndex;
  uint8_t       State;
  uint8_t       SavedState;
  int16_t       Prev;
  int16_t       AccumError;
  int16_t       Voltage_Peak;
  int16_t       TempPrev;
  uint16_t      Timer;
  uint32_t      mAS;
 } Charge_State;

#define BUTTON_CH(X)            (2-(X))

// fixed point scaling
#define VOLT(X)                 ((X)*1000.0)
#define AMP(X)                  ((X)*1000.0)
#define C_PERCENT(X,Y)          ((long)X*Y/100)

void Battery_LoadProfile(uint8_t Chan, const void * Addr);
void Charger_Init(void);
void Charger_Off(uint8_t Ch, uint8_t State);
void Charge_Icon(uint8_t State);
void Charge_Status(void);
void Charger_PID(int16_t Actual, int16_t Error, uint8_t Ch, int8_t Gain);
void Charger_CC(int16_t Current, uint8_t Chan);
void Charger_CV(uint16_t Volt, uint8_t Chan);
void ChargerTask(void);
uint8_t Battery_Select(void);

extern xdata Charge_State Charger_CH[CHARGERS];
extern uint8_t Update_Cnt, Timer_Enable;

#define TIMER1_ENABLE           0x01
#define TIMER2_ENABLE           0x02
#define TIMER_ENABLE(X)         (1<<X)

#define TimerEnable(X)          Timer_Enable |= TIMER_ENABLE(X)
#define TimerDisable(X)         Timer_Enable &= ~TIMER_ENABLE(X)

#define PRECHARGE_TIMEOUT       (0.5 * Hour)
#define OVERCHARGE              (1.1 * Hour)

#define OVERVOLT                500

// Improves on stability when both chargers are on
#define I_DeadZone              0x03

#define Int_Error_Range         0x10
#define ErrorLimit_I            0x80

// PID parameters
#define PID_CC_GAIN             128		// 1/200
#define PID_CC_DSCH_GAIN        -512	        // 1/-25
#define PID_CV_GAIN             64		// 1/2000

// CC 110, 10, 50 for 768mA ~ 10% overshoot
// CC 90, 10, 50 for 768mA ~ 5% overshoot
// CC 60, 10, 60 for 768mA ~ 1.4% overshoot

// CC 40, 20, 40 for 768mA

#define PARM_P		        32
#define PARM_I		        2L
#define PARM_D		        16L

enum GAINS { DSCHRG_GAIN, CC_GAIN, CV_GAIN };

extern code const BatteryType Batteries[];
#endif /* BATTERY_H_ */

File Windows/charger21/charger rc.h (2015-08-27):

#define IDD_DIALOG1		1

#define IDC_DBG			108


#define IDC_ReportLevel		116
#define IDC_SaveLog		117
#define IDC_ClearLog		118


#define IDM_MENU2		2

#define CM_SaveAs		204
#define CM_Open			206
#define CM_New			207
#define CM_Exit 		208

#define CM_SaveLog		300
#define CM_Clr_Log		301

#define CM_Log_Everything	307
#define CM_Log_Debug		306
#define CM_Log_Verbose		305
#define CM_Log_Warnings		304
#define CM_Log_Errors		303
#define CM_Log_None		302

#define IDC_CHARGER		3
#define IDD_CONSOLE		4
#define IDD_BATTERY		5

#define IDC_Grp_Log  		100

#define IDC_ChargerStatus  	4009
#define IDC_Graph  		4001
#define IDC_ScrollX		4002
#define IDC_ScrollY		4003
#define IDC_ZOOM_ALL  		4004
#define IDC_Tab			4005
#define IDC_Status_Bar		4006


#define IDC_VIN  		4012
#define IDC_ChargerStatus0  	4010
#define IDC_ChargerStatus1  	4011
#define IDC_ReceiveData0  	4015
#define IDC_ReceiveData1  	4016
#define IDC_Battery0  		4007
#define IDC_Battery1  		4014
#define IDS_Status  		4017

#define IDC_ADD  		4019
#define IDC_Remove  		4020
#define IDC_Precharge_Grp  	4022
#define IDC_Charge  		4023
#define IDC_Top_Up_Grp  	4024
#define IDC_Capacity_Lbl  	4027
#define IDC_mAH_Lbl  		4028
#define IDC_BattType_Lbl  	4029
#define IDC_Name_Lbl  		4030
#define IDC_Capacity  		4026
#define IDC_PreChargeV  	4031
#define IDC_PrechargeI  	4032
#define IDC_PV_Lbl  		4033
#define IDC_PI  		4034
#define IDC_ChargeV  		4035
#define IDC_ChargeI  		4036
#define IDC_CV_Lbl  		4037
#define IDC_CI_Lbl  		4038
#define IDC_TopUpV  		4039
#define IDC_TopUpI  		4040
#define IDC_TUV_Lbl  		4041
#define IDC_TUI_Lbl  		4042
#define IDC_Capacity_mAH_Lbl  	4043
#define IDC_Batt_Name  		4021
#define IDC_Batt_Type  		4025
#define IDC_Charger0_But  	4044
#define IDC_Charger1_But  	4045
#define IDC_Charger_State0  	4046
#define IDC_Charger_State1  	4047
#define IDC_BatteryScroll  	4048
#define IDD_StatusBar  		4018
#define IDC_Update  		4049
#define IDC_Volt0  		4008
#define IDC_Volt1  		4013
#define IDC_Current0  		4050
#define IDC_Current1  		4051
#define IDC_Temp0  		4052
#define IDC_Temp1  		4053
#define IDC_Timer1  		4054
#define IDC_Timer0  		4055
#define IDC_Sync  		4056

#define IDI_Icon  		8001

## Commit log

2015-07-23 Initial Commit - PCB Ordered/Release - non tested
    [Dual v12.brd, Dual v12.sch]
2015-07-23 Add LTSpice,, pdf schematic
    [Dual v12.brd, Dual v12.sch]
2015-08-27 Initial Windows Most Software release
    [Battery gui.obj, Charger gui.obj, charger.obj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]
2015-09-12 added BOM
    [Dual v12.brd, Dual v12.sch]
2015-09-12 added BOM - take 2
    [Dual v12_ListByValues.csv]

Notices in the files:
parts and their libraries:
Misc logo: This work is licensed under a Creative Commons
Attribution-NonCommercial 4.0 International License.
